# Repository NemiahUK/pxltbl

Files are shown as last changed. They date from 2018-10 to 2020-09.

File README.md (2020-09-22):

# Pixel Table 2.0 - Beta

Pixel Table

The API comes with a browser-based Emulator so you don’t need to build the table just yet.

## Try it out now - no hardware required!

You can now run the web-based emulator from any machine: Windows, Linux, Mac or RasPi. Follow the quick start guide and create 
progs that will run on a physical Pixel Table and play with them using a virtual Pixel Table in your browser. 

[Quick Start Guide](https://github.com/NemiahUK/pxltbl/blob/master/docs/getting-started.md)

## Costs

You have several options including software-only, table-top and full-sized. Each of these options can be done to different
levels of complexity and cost. Here's a rough guide to each option, a full bill of materials (BOM) can be found [HERE](https://docs.google.com/spreadsheets/d/1ZHOPDPXH3Y888mUGACTdFI8b1-cgUbUthqjndGLfB64).

### Software only - FREE

You can just download the API and use it on any machine via a web-browser. In future there will be a 'fullscreen' mode so that you 
can emulate the table top exactly as it would be on an actual pxltbl.

### PxlTbl Mini - £100 to £200

A table-top-sized device using a Raspberry Pi, 7" touchscreen and 3D printed case. You can add an audio HAT and arcade buttons too. 

### PxlTbl - £700 to £1,000

The full-sized version, over 1m long and 40cm high with a 50" touch screen. You can add a 200W stereo amp, car speakers, arcade buttons and
a real wood frame for an amazing looking and sounding piece of furniture. Or just keep things simple and costs low.

## Skills needed

Everything you need and where to buy them from will be listed in the [BOM](https://docs.google.com/spreadsheets/d/1ZHOPDPXH3Y888mUGACTdFI8b1-cgUbUthqjndGLfB64). You won't need to do any cutting, welding or custom 
fabrication, it's all based around pieces that can be ordered to size and bolted together. You will need to know how to solder
and if you have access to a 3D printer, laser cutter or CNC machine you can make the parts yourself instead of ordering them online.

## BIG plans

It's early days yet, but we have lots of great ideas. You can build "progs" using your web browser right now, then when we 
release the full build guid you can build your own table. 

## Hardware guide coming soon

We'll also be releasing a full guide on how to build your own Pixel Table using a RasPi + Arduino + NeoPixels. It's fairly straight
forward, and once built, you can use this API to make programming your table super-easy!

## API reference

[Full API reference (work in progress)](https://github.com/NemiahUK/pxltbl/blob/master/docs/api-reference.md) 

## Follow us

[Facebook](https://facebook.com/nemiah) - [Twitter](https://twitter.com/nemiahUK)

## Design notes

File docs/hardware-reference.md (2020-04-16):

# Hardware Reference

## GPIO Pins

                   3V3 -  1 2  - Arduino +5V
           Arduino SDA -  3 4  - Amp +5V
           Arduino SCL -  5 6  - Arduino GND
                       -  7 8  - Arduino UART Rx (Pin0)
               Amp GND -  9 10 - Arduino UART Tx (Pin1)
         Arduino Reset - 11 12 - Amp BCLK / Analog PWM L
             Button RT - 13 14 - GND
             Button TR - 15 16 - Button LB
            Button 3V3 - 17 18 - Button BL
                  MOSI - 19 20 - GND
                  MISO - 21 22 - Button LT
                  SCLK - 23 24 - CE0
                   GND - 25 26 - CE1
                       - 27 28 -
                       - 29 30 - GND
           Button Home - 31 32 - Button BR
          Analog PWM R - 33 34 - GND
             Amp LRCLK - 35 36 - Button RB
             Button TL - 37 38 - 
                   GND - 39 40 - Amp DIN

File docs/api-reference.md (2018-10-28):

# API Reference

## API functions

There are two ways to use the api.

#### Method 1 - Using "progs" via index.js

This is the simplest way to get up and running. Pixel Table has a basic "operating system" - index.js. This creates
a menu allowing you to run all the scripts in the progs/ directory. As well as providing easy access to settings. It 
also inculdes the API and makes it avaiable to your scripts in a simple way.

If you use this method, you simply create your script as-per the hello world example and upload it to the progs folder. 
You don't need to restart the running node process, you just go back to the home screen menu and select your prog. The 
system will reload your script from the file system and run it.

You don't need to initialise the api, you just put your code inside the setup() and loop() functions in your script.

    // Hello world example prog.

    // Put variables here that you need to persist between loops.
    var message = 'Hi =]';
    
    exports.setup = function(api) {
        // Code here get's executed once at program startup.
    
        // Blank the screen
        api.blank(0, 0, 0);
    };
    
    exports.loop = function(api) {
    
        // Set the drawing colour.
        api.setColor(0, 255, 0);
    
        // Print some text.
        api.text(message, 1,2);
    
        // If fire button pressed then exit back to home screen.
        if(api.buttons.topLeft) api.exit();
        
    };

Eventually you will also be able to create and upload progs via the web interface.

#### Method 2 - Creating your own script and including the API

If you don't want to use the menu system and have access to other progs etc you can just include the API. This way only
your script will run and you have more control over the system.

To initialise the API...

### start(options)

Initialises the API and returns a reference to it. The minimum you need is to set an FPS limit and callback function e.g.

    const api = require('./api.js');
    
    api = api.start({
        callbackLoop: myLoop,
        fpsLimit: 30
    });

The function myLoop() will then be called 30 times a second.

##### The options are...

 **callbackLoop** (function) *required - The function to call every frame
 
 **fpsLimit** (number) *recomended - The maximum FPS allowed. You can omit this or set to 0 but it's not advised, a 
 RasPi 3 runs around 100fps but without setting a limit animations will not be consistent unless you use time-based
 maths to animate things.
 
 **consoleData** (boolean) default: true - If true then show stats in console (updated every 500ms).
 
 ---
 
Whichever method you use, these functions can be used at any point.
 
### setFpsLimit(fps) 

Sets the FPS limit to fps.

---

### setRotation(angle)

Rotates both the display and buttons in 90deg increments.

The only valid options for angle are: 0, 90, 180 or 270.

---

### exit() 

Returns to the home screen - this only works if you are using the API from a prog called via index.js

---

### debug(string/object/array)

Outputs whatever is passed to it to the web interface as a debug message.

---

### error(string/object/array)

Outputs whatever is passed to it to the web interface as an error message.

---

### isRasPi

true if running on a Raspberry Pi, otherwise false.

---

### millis

Number of milliseconds since start, useful for time based animations and interactions.

---

### fps

Current FPS, 1 second average.

---

### frameTime

Last frame time in ms.

---

### pxlW

The width of the display in pixels.

---

### pxlH

The height of the display in pixels.

---

### pxlCount

The number of pixels in the display.

---

### pxlH

The height of the display in pixels.

## Drawing functions

For most draw functions you must first set the colour using setColor(), whatever colour is set will persist until 
setColor() is called again.

Pixel 0,0 is the top left pixel with the co-ordinates increasing in value as you move right or down.

The entire display can be rotated in 90deg increments using rotate() this will change the physical position of pixel 
0,0 accordingly.

### blank(r,g,b)
Fills the screen with the selected colour.

---

### setColor(r,g,b,[a])
Sets the drawing colour. 

`r,g,b` are values 0-255. `a` is optional, in the range of 0-1, default 1.0

---

### setColor(string)  *not yet implemented*
Sets the drawing colour.

String must be HTML/CSS Hex colour code. e.g. `#DECAFF`

---

### setColor(array)
Sets the drawing colour.

Expects an array of 3 or 4 elements...

    [0] = r    0-255
    [1] = g    0-255
    [2] = b    0-255
    [3] = a    0.0-1.0

---

### setColor(object)
Sets the drawing colour.

Possible object properties are...

RGB format

    {
        r : 0-255
        g : 0-255
        b : 0-255
        a : 0.0-1.0    //optional - default 1.0
    }
HSL format

    {
        h : 0-360
        s : 0-255
        l : 0-255
        a : 0.0-1.0    //optional - default 1.0
    }
HSV format

    {
        h : 0-360
        s : 0-255
        v : 0-255
        a : 0.0-1.0    //optional - default 1.0
    }

---

### setColorHsl(h,s,l,a)
Sets the drawing colour. 

`h` is 0-360, `s,l` are 0-255. `a` is optional, in the range of 0-1, default 1.0

---

### setColorHsv(h,s,v,a)
Sets the drawing colour. 

`h` is 0-360, `s,v` are 0-255. `a` is optional, in the range of 0-1, default 1.0

---

### fillBox(x,y,w,y)

Draws a filled box at location `x,y` of width `w` and height `h`

---

### text(text,x,y)

Draws `text` starting with the upper left corner of the first character at location `x,y`.

Returns an object containing the width and height of the bounding box containing the text.

    {
        w : width,
        h : height
    }

---

### textBounds(text)

Returns an object containing the width and height of the bounding box containing the text.

    {
        w : width,
        h : height
    }

---

## Input functions

Pixel table uses 8 control buttons at the corners of the table. These are named by the side they are on first 
followed by where they are on that side. So topLeft is on the TOP side at the LEFT and leftTop is on the LEFT side
at the TOP.

The top left button is where pixel 0,0 is located, it is not tied to a physical button. If the display is rotated (rotate()) then the names of the buttons will change
to match the device orientation, so topLeft will now be a different physical button, but it will still be where pixel 0,0 is.

### clearInputs()

Sets all buttons to false and clears all touch data.

---

### buttons

This variable is an object containing all the button states (true or false).

    {
        topLeft: true/false,
        leftTop: true/false,
        topRight: true/false,
        rightTop: true/false,
        rightBottom: true/false,
        bottomRight: true/false,
        bottomLeft: true/false,
        leftBottom: true/false,
        top: true/false,           // either top button has been pressed
        bottom: true/false,        // either bottom button has been pressed
        left: true/false,          // either left button has been pressed
        right: true/false,         // either right button has been pressed
        any: true/false            // any button has been pressed
    };
    
---

## Sound functions

### playWav(file,loop)

Plays a WAV file located in the `wav/` folder. There are over 500 wavs included in this repo and you can add your own.

file is just the filename without any path or extension. e.g. `sfx_damage_hit1`  will play `./wav/sfx_damage_hit1.wav`

If you set loop to true the WAV will continue to play until stopped. 

This function returns a reference that can be used to stop the playback. e.g.

    myPlayer = api.playWav('sfx_damage_hit1',true);
    ...
    myPlayer.stop();

## Helper functions

#### rgbToHsv(r,g,b)

---

#### hsvToRgb(h,s,v)

---

#### rgbToHsl(r,g,b)

---

#### hslToRgb(h,s,l)

To be continued....

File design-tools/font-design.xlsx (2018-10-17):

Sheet: lowercase
a | 1
 | 2
 | 4
 | 8 | 1 | 1 | 1 | 1 | 1
 | 16 |  |  |  |  | 1
 | 32 | 1 | 1 | 1 | 1 | 1
 | 64 | 1 |  |  |  | 1
 | 128 | 1 | 1 | 1 | 1 | 1
 | 61 | E8 | A8 | A8 | A8 | F8 | 61 | E8 | A8 | A8 | A8 | F8 | a
b | 1
 | 2 | 1
 | 4 | 1
 | 8 | 1 | 1 | 1 | 1 | 1
 | 16 | 1 |  |  |  | 1
 | 32 | 1 |  |  |  | 1
 | 64 | 1 |  |  |  | 1
 | 128 | 1 | 1 | 1 | 1 | 1
 | 62 | FE | 88 | 88 | 88 | F8 | 62 | FE | 88 | 88 | 88 | F8 | b
c | 1
 | 2
 | 4
 | 8 | 1 | 1 | 1 | 1 | 1
 | 16 | 1
 | 32 | 1
 | 64 | 1
 | 128 | 1 | 1 | 1 | 1 | 1
 | 63 | F8 | 88 | 88 | 88 | 88 | 63 | F8 | 88 | 88 | 88 | 88 | c
d | 1
 | 2 |  |  |  |  | 1
 | 4 |  |  |  |  | 1
 | 8 | 1 | 1 | 1 | 1 | 1
 | 16 | 1 |  |  |  | 1
 | 32 | 1 |  |  |  | 1
 | 64 | 1 |  |  |  | 1
 | 128 | 1 | 1 | 1 | 1 | 1
 | 64 | F8 | 88 | 88 | 88 | FE | 64 | F8 | 88 | 88 | 88 | FE | d
e | 1
 | 2
 | 4
 | 8 | 1 | 1 | 1 | 1 | 1
 | 16 | 1 |  |  |  | 1
 | 32 | 1 | 1 | 1 | 1 | 1
 | 64 | 1
 | 128 | 1 | 1 | 1 | 1 | 1
 | 65 | F8 | A8 | A8 | A8 | B8 | 65 | F8 | A8 | A8 | A8 | B8 | e
f | 1
 | 2 | 1 | 1 | 1 | 1
 | 4 | 1
 | 8 | 1 | 1 | 1
 | 16 | 1
 | 32 | 1
 | 64 | 1
 | 128 | 1
 | 66 | FE | A | A | 2 | 0 | 66 | FE | A | A | 2 | 0 | f
g | 1 | 1 | 1 | 1 | 1 | 1
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

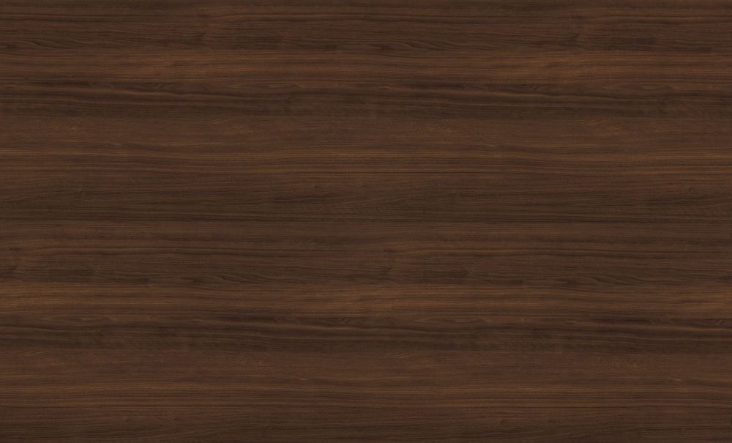
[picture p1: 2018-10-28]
api/web/bg.jpg

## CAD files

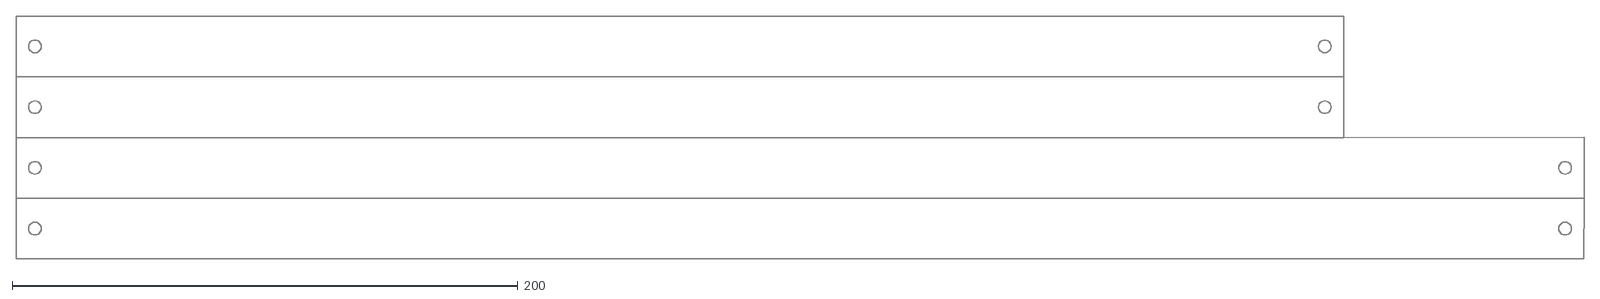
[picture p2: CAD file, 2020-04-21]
3d-print/short-side-panels-3mm.dxf
620.0 x 96.0

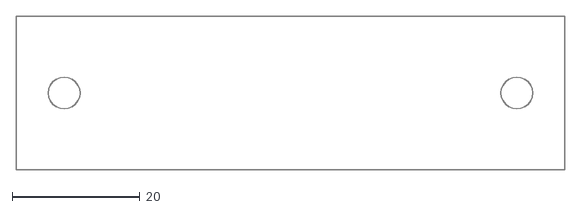
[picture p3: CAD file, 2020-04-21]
3d-print/short-side-panels-3mm-test.dxf
86.0 x 24.0

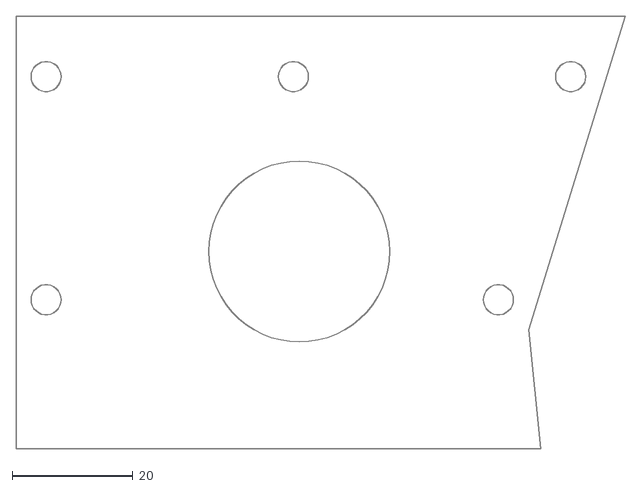
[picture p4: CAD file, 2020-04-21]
3d-print/short-side-panels-5mm-test.dxf
101.0 x 71.7

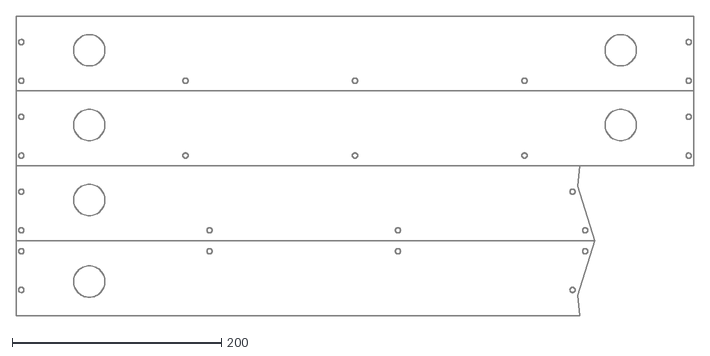
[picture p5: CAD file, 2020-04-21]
3d-print/short-side-panels-5mm.dxf
648.0 x 286.4

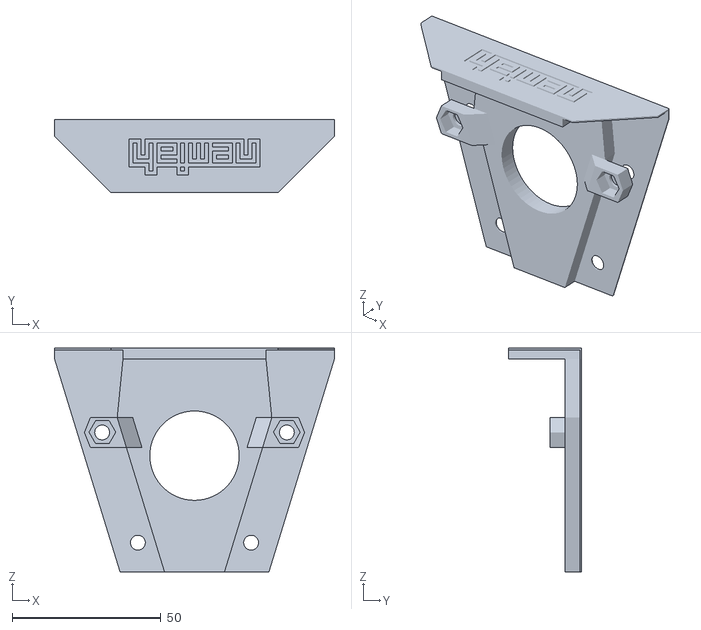
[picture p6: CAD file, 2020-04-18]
3d-print/short-button-joint.stl
94.0 x 24.6 x 75.1

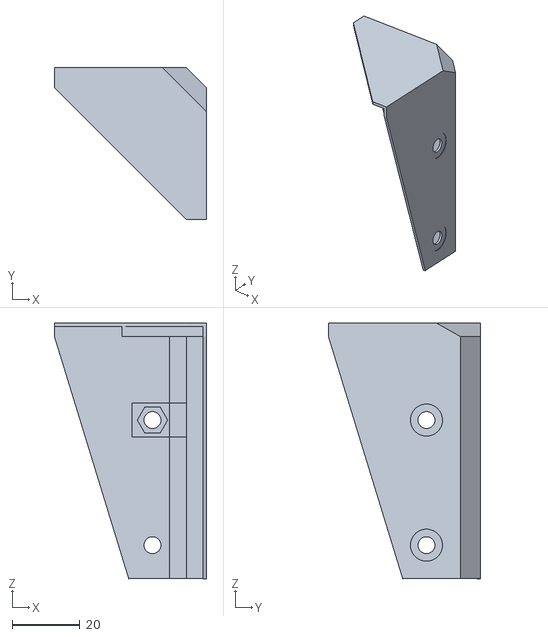
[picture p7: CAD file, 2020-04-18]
3d-print/short-corner-with-bracket.stl
45.0 x 45.0 x 75.7

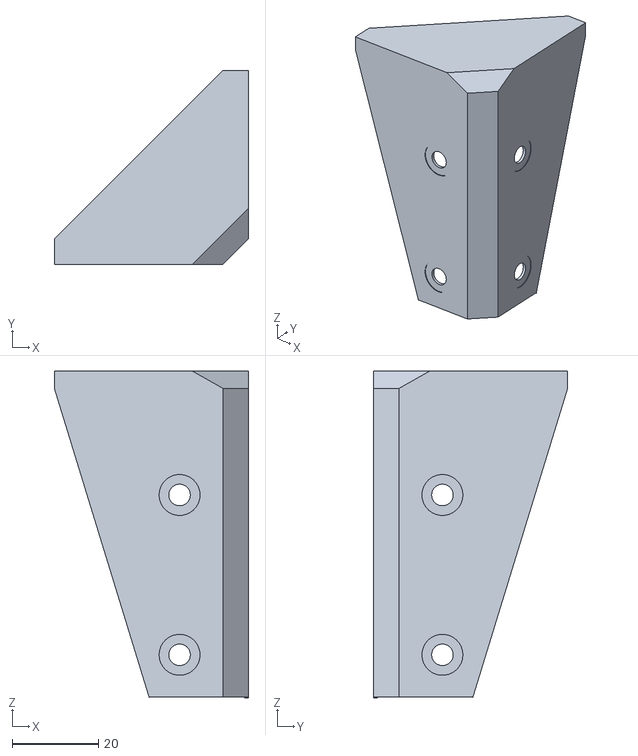
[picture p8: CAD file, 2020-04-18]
3d-print/short-corner.stl
45.0 x 45.0 x 75.7

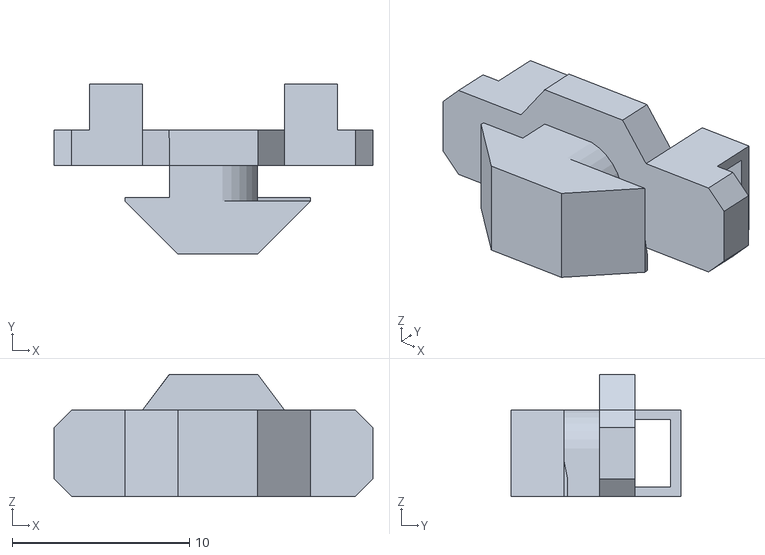
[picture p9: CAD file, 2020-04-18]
3d-print/cable-clip-5mm-slot.stl
18.0 x 9.60 x 6.89

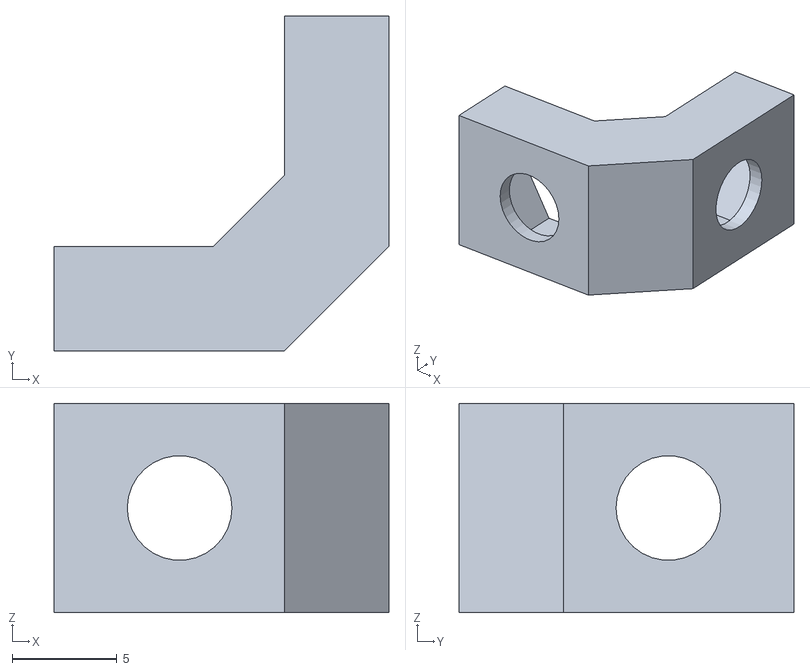
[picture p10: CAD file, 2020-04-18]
3d-print/M5-corner-bracket.stl
16.0 x 16.0 x 10.0

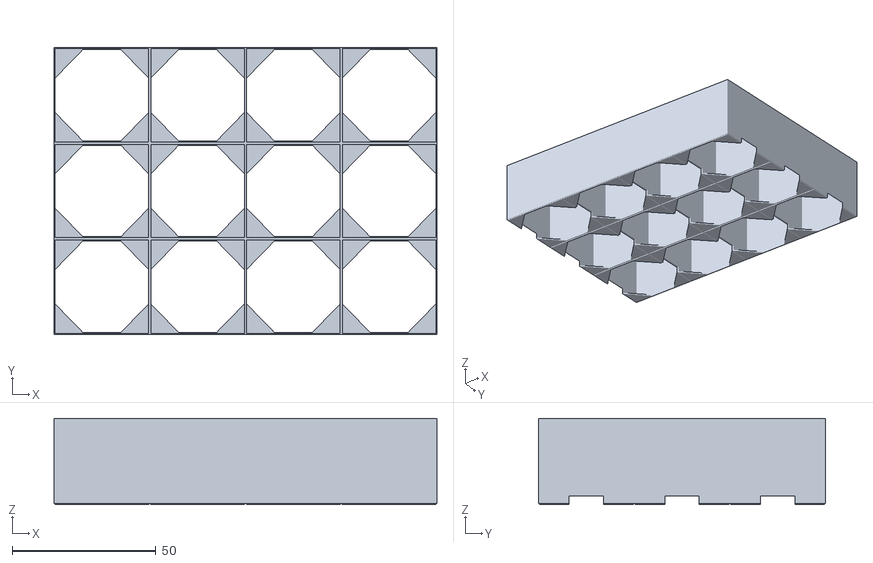
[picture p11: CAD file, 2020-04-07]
3d-print/reflector-33.3mm-30mm-4x3.stl
133.4 x 100.0 x 30.0

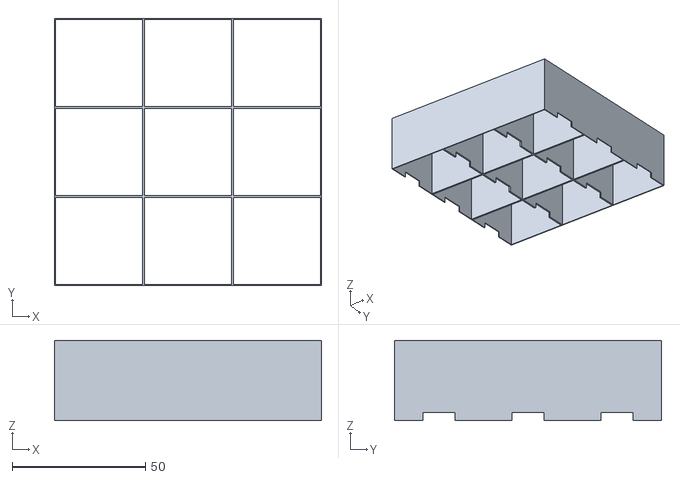
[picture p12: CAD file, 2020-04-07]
3d-print/reflector-33.3mm-30mm-3x3.stl
100.0 x 100.0 x 30.0

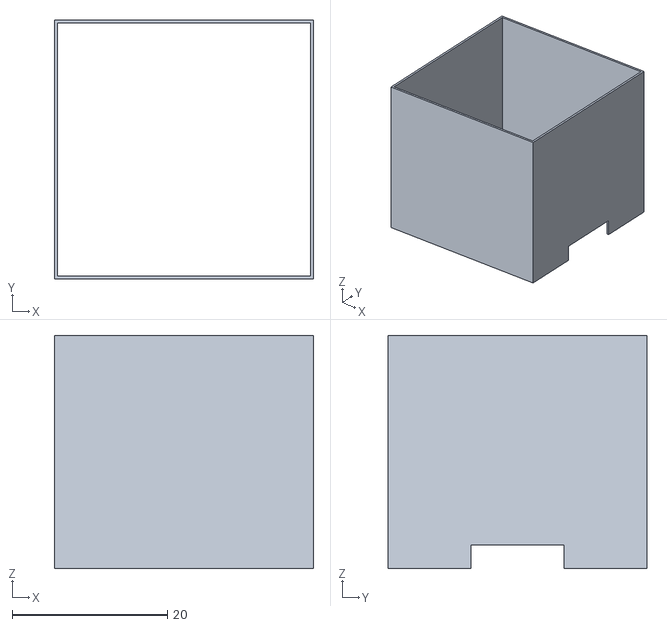
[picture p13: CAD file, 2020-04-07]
3d-print/reflector-33.3mm-30mm.stl
33.3 x 33.3 x 30.0

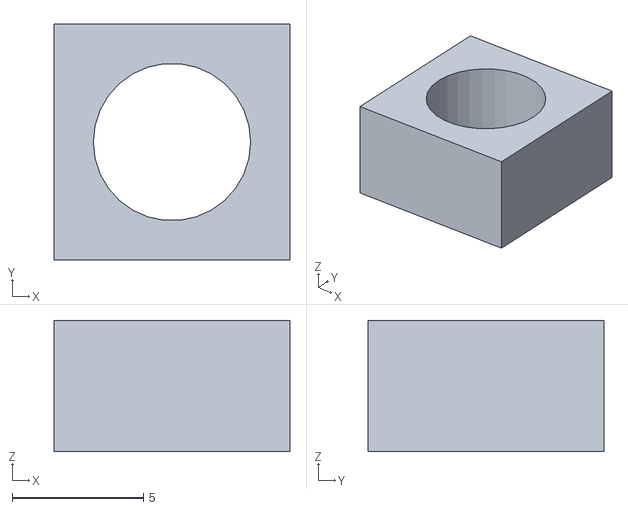
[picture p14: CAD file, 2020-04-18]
3d-print/M5-5x9x9mm-washer.stl
9.00 x 9.00 x 5.00

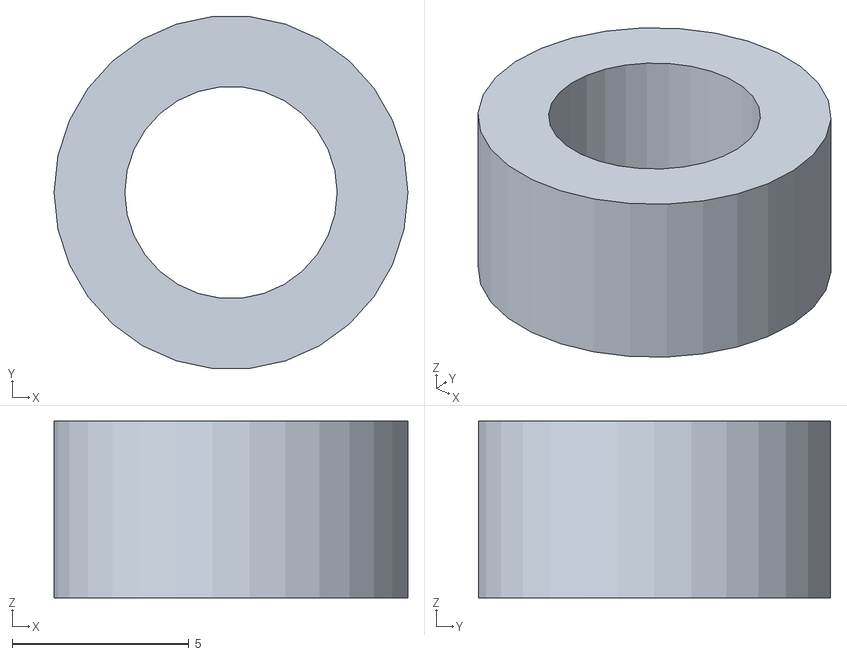
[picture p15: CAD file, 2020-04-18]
3d-print/M5-5x2mm-washer.stl
10.0 x 9.95 x 5.00

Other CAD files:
3d-print/full-model.skp
3d-print/wire-guide.skp

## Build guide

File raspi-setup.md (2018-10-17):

#RasPi Setup
##Enable audio over GPIO

add the following to /boot/config.txt: 

    dtoverlay=pwm-2chan,pin=18,func=2,pin2=13,func2=4

##Set screen res to 1600x900
Why? becasue this works really well for VNC on a 1080p monitor and is wide enough to display the LED buffer.

add the following to /boot/config.txt: 

    hdmi_group=2
    hdmi_mode=83

##RasPi config:

Enable SSH
Enable VNC
Enable I2C
Enable SPI
Enable Serial Port
Disable Serial Console

##Other config

Disable boot info (may already been done), edit this file: /boot/cmdline.txt and look for something liek this
    dwc_otg.lpm_enable=0 console=serial0,115200 console=tty1 root=/dev/mmcblk0p6 rootfstype=ext4 elevator=deadline rootwait

Delete the "console=serail0,115200" part.

##Install

###Arduino (in future this may be handled by node)

    sudo apt-get install arduino

###Arduino auto-reset script (in future this may be handled by node)

    cd ~
    wget https://github.com/SpellFoundry/avrdude-rpi/archive/master.zip
    sudo unzip master.zip
    cd ./avrdude-rpi-master/
    sudo cp autoreset /usr/bin
    sudo cp avrdude-autoreset /usr/bin
    sudo mv /usr/bin/avrdude /usr/bin/avrdude-original
    sudo ln -s /usr/bin/avrdude-autoreset /usr/bin/avrdude

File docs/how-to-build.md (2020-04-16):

# How to build the PxlTbl
## Coming soon...

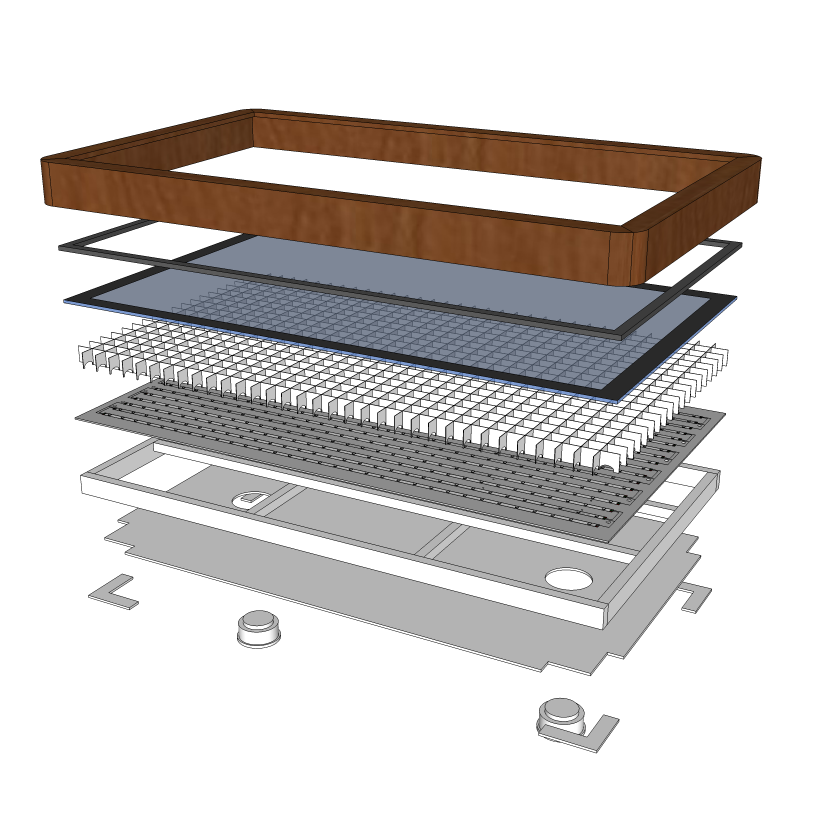
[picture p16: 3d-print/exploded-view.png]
Exploded view


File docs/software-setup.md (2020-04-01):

# RasPi Setup
## Enable audio over I2S

Follow the instructions here: https://learn.adafruit.com/adafruit-max98357-i2s-class-d-mono-amp/raspberry-pi-usage

## Set screen res to 1600x900
Why? becasue this works really well for VNC on a 1080p monitor and is wide enough to display the LED buffer.

add the following to /boot/config.txt: 

    hdmi_group=2
    hdmi_mode=83

## RasPi config:

* Enable SSH
* Enable VNC
* Enable I2C
* Enable SPI
* Enable Serial Port
* Disable Serial Console

## Other config

Disable boot info (this is usually already done), edit this file: `/boot/cmdline.txt` and look for something like this
    `dwc_otg.lpm_enable=0 console=serial0,115200 console=tty1 root=/dev/mmcblk0p6 rootfstype=ext4 elevator=deadline rootwait`

Delete the `console=serail0,115200` part.

## Enable auto run as service

Find out where npm is installed by typing `which npm` it should return `/usr/bin/npm` or `/usr/local/bin/npm` make a note of this.

Create the service file...

    sudo nano /etc/systemd/system/pxltbl.service

Paste the following:

    [Unit]
    Description=Pixel Table service
    After=network.target

    [Service]
    ExecStart=/usr/bin/npm start
    WorkingDirectory=/home/pi/pxltbl/api
    StandardOutput=inherit
    StandardError=inherit
    Restart=on-failure
    User=root

    [Install]
    WantedBy=multi-user.target

Change the line `ExecStart=/usr/bin/npm start` to match the npm path you noted down earlier.

Enable the service

    sudo systemctl enable pxltbl.service
   
Start the service

    sudo systemctl start pxltbl.service
    
If you want to view the logs

    journalctl -u pxltbl

## Install

### Prerequisites for node-hid

Compilation tools: 

    sudo apt-get install build-essential git

gcc-4.8+: 

    sudo apt-get install gcc-4.8 g++-4.8 && export CXX=g++-4.8

libusb-1.0-0 w/headers:

    sudo apt-get install libusb-1.0-0 libusb-1.0-0-dev

libudev-dev: 

    sudo apt-get install libudev-dev

### Arduino (in future this may be handled by node)

    sudo apt-get install arduino

### Arduino auto-reset script (in future this may be handled by node)

    cd ~
    wget https://github.com/SpellFoundry/avrdude-rpi/archive/master.zip
    sudo unzip master.zip
    cd ./avrdude-rpi-master/
    sudo cp autoreset /usr/bin
    sudo cp avrdude-autoreset /usr/bin
    sudo mv /usr/bin/avrdude /usr/bin/avrdude-original
    sudo ln -s /usr/bin/avrdude-autoreset /usr/bin/avrdude

## Reference

### GPIO Pins

                   3V3 -  1 2  - Arduino +5V
           Arduino SDA -  3 4  - Amp +5V
           Arduino SCL -  5 6  - Arduino GND
                       -  7 8  - Arduino UART Rx (Pin0)
               Amp GND -  9 10 - Arduino UART Tx (Pin1)
         Arduino Reset - 11 12 - Amp BCLK / Analog PWM L
             Button RT - 13 14 - GND
             Button TR - 15 16 - Button LB
            Button 3V3 - 17 18 - Button BL
                  MOSI - 19 20 - GND
                  MISO - 21 22 - Button LT
                  SCLK - 23 24 - CE0
                   GND - 25 26 - CE1
                       - 27 28 -
                       - 29 30 - GND
           Button Home - 31 32 - Button BR
          Analog PWM R - 33 34 - GND
             Amp LRCLK - 35 36 - Button RB
             Button TL - 37 38 - 
                   GND - 39 40 - Amp DIN

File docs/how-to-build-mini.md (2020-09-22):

# How to build the PxlTbl mini

# RasPi Setup

## Set screen res to 1024x600

Add the following to /boot/config.txt: 

    hdmi_cvt=1024 600 60 3 0 0 0
    hdmi_group=2
    hdmi_mode=87

## Using RasPi config:

* Enable SSH
* Enable VNC
* Enable Serial Port
* Disable Serial Console

## Other config

Disable boot info (this is usually already done), edit this file: `/boot/cmdline.txt` and look for something like this
    `dwc_otg.lpm_enable=0 console=serial0,115200 console=tty1 root=/dev/mmcblk0p6 rootfstype=ext4 elevator=deadline rootwait`

Delete the `console=serail0,115200` part.

## Setup audio shield

Follow the instructions at: https://learn.adafruit.com/adafruit-speaker-bonnet-for-raspberry-pi/raspberry-pi-usage

You need to complete the extra tasks on the I2S Tweaks page to get audio to work properly.

## Install

### Install node/npm

TODO

### Prerequisites for node-hid 

Compilation tools: 

    sudo apt-get install build-essential git

gcc-4.8+: 

    sudo apt-get install gcc-4.8 g++-4.8 && export CXX=g++-4.8

libusb-1.0-0 w/headers:

    sudo apt-get install libusb-1.0-0 libusb-1.0-0-dev

libudev-dev: 

    sudo apt-get install libudev-dev
    
## Configure pxltbl

Edit config.json and set `serialEnabled : false`

## Enable auto run as service

Copy service file

    sudo cp /home/pi/pxltbl/scripts/pxltbl.service /etc/systemd/system/pxltbl.service

Enable the service

    sudo systemctl enable pxltbl.service
   
Start the service

    sudo systemctl start pxltbl.service
    
If you want to view the logs

    journalctl -u pxltbl
    
## Disable screen blanking and pointer 
    sudo apt-get install unclutter xscreensaver        
  
##  Setup Chromium kiosk and auto boot  
Edit LXDE autostart
    
    sudo nano /etc/xdg/lxsession/LXDE-pi/autostart

add line
    
    @bash /home/pi/pxltbl/scripts/pxltbl-mini.sh
    
Change desktop background

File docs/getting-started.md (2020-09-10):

# Getting Started
#### A quick guide to setting up Pixel Table on your PC and creating your first prog.

Pixel Table Emulator

If you just want to use the web-based emulator instead of building your own Pixel Table, then this is the guide for you.

Pixel Table is designed to run on a Raspberry Pi 3+, but it should run on any platform that Node supports. We've tested it on Windows 10.

* Check to see if Node is already installed by typing `node -v` into the console
* If needed, Install Node.js you want the LTS version (currently v12) https://nodejs.org/en/download/ or 
in Ubuntu you can run the following command in terminal to install automatically `curl -sL https://deb.nodesource.com/setup_12.x | sudo -E bash -` then `sudo apt-get install -y nodejs npm` 
* *EITHER* install git (if needed) the clone the repo by typing  `git clone https://github.com/TmpR/pxltbl.git`
* *OR* Download the zip file from https://github.com/TmpR/pxltbl/archive/master.zip and extract it
* Navigate to the project directory and enter the sub-folder `api/` 
* Type `npm install`
* To run the app type `node index.js`
* Visit http://127.0.0.1:3000 in your browser

## Adding your own progs

* Navigate to the subfolder `progs/`
* Copy the `hello-world.js` file to `your-prog.js` create your own prog.

See https://github.com/NemiahUK/pxltbl/blob/master/docs/api-reference.md for more info on how to use the API.

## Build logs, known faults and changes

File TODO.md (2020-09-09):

# PxlTbl API Todo's

### Ideas

### TODO

- [ ] Move old 'package.json' and remove old node folder. Make sure new set up is working correctly.

### In Progress

### Done ✓

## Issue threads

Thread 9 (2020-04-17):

Sometimes when powering on Teensy crashes

Tmp2k, 2020-04-17:

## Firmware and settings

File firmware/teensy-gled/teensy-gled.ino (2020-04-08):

#include <OctoWS2811.h>


//OctoWS2811 Defn. Stuff
#define COLS_LEDS 32  
#define ROWS_LEDS 24  
#define SCREEN_ROWS_LEDS 18
#define RGB_ORDER "RGB"

#define LEDS_PER_STRIP (COLS_LEDS * (ROWS_LEDS / 8))
const int NUM_LEDS = (COLS_LEDS * ROWS_LEDS);

DMAMEM int displayMemory[LEDS_PER_STRIP*6];
int drawingMemory[LEDS_PER_STRIP*6];

const int config = WS2811_GRB | WS2811_800kHz;
OctoWS2811 leds(LEDS_PER_STRIP, displayMemory, drawingMemory, config);

//Params and global variables
#define LOGO_COLOR #CCCCCC
#define BAUD 1000000

unsigned long lastSerialRead = 0;


//Logo anim stuff
#define ANIM_FPS 40
int pxl = 0;
unsigned long lastFrameTime = 0;
unsigned int paintColor;
int logoX, logoY, logoScroll, yPos;
float xPos = -7, xScroll = 0;
int animState = 0;

//rainbow colors..
//Hue => [0,45,65,135,210,260,270]
byte rainbowR[] = {255, 255, 234,   0,   0,  85, 128};
byte rainbowG[] = {  0, 191, 255, 255, 128,   0,   0};
byte rainbowB[] = {  0,   0,   0,  64, 255, 255, 255};


void setup() {
  
  Serial1.begin(BAUD);
  //Serial.begin(BAUD);
  leds.begin();
  leds.show();
}

int serialGlediator() {
  while (!Serial1.available() && !Serial.available()) {
    if(millis() - lastSerialRead > 1000) showLogo();
  }
  if(Serial.available()) {
    resetLogo();
    return Serial.read();
  } else {
    resetLogo();
    return Serial1.read();
  }
}



void loop() {
  
  byte mode = 0;

  while (serialGlediator() != 1) {}
  mode = serialGlediator();

  switch (mode) {
    case 0x2:
      readFrame();
      break;
    case 0x3:
      returnInfo();
      break;
  }
}



void resetLogo() {
  lastSerialRead = millis();
  xPos = -7;
  xScroll = 0;
}

void showLogo() {
  int i,j,y;

  if(millis() - lastFrameTime < 1000 / ANIM_FPS) return;  //40FPS
  lastFrameTime = millis();
 
  blank(0x000000);

  yPos = SCREEN_ROWS_LEDS / 2 - 3;  //Approx horz middle of screen - 1/2 logo height

  logoX = round(xPos);
  logoScroll = round(xScroll);
  logoY = round(yPos);
  if(logoX % 6 < 3) logoY--;

  //logo
  paintColor = 0x333333;
  setPixel(logoX-logoScroll,logoY+0); setPixel(logoX-logoScroll+1,logoY+0); setPixel(logoX-logoScroll+2,logoY+0); setPixel(logoX-logoScroll+3,logoY+0); setPixel(logoX-logoScroll+4,logoY+0); setPixel(logoX-logoScroll+5,logoY+0); setPixel(logoX-logoScroll+6,logoY+0);
  setPixel(logoX-logoScroll,logoY+1); setPixel(logoX-logoScroll+6,logoY+1); 
  setPixel(logoX-logoScroll,logoY+2); setPixel(logoX-logoScroll+2,logoY+2); setPixel(logoX-logoScroll+3,logoY+2); setPixel(logoX-logoScroll+4,logoY+2); setPixel(logoX-logoScroll+6,logoY+2);
  setPixel(logoX-logoScroll,logoY+3); setPixel(logoX-logoScroll+2,logoY+3); setPixel(logoX-logoScroll+4,logoY+3); setPixel(logoX-logoScroll+6,logoY+3);
  setPixel(logoX-logoScroll,logoY+4); setPixel(logoX-logoScroll+2,logoY+4); setPixel(logoX-logoScroll+4,logoY+4); setPixel(logoX-logoScroll+6,logoY+4);
  setPixel(logoX-logoScroll,logoY+5); setPixel(logoX-logoScroll+2,logoY+5); setPixel(logoX-logoScroll+4,logoY+5); setPixel(logoX-logoScroll+6,logoY+5);
  setPixel(logoX-logoScroll,logoY+6); setPixel(logoX-logoScroll+1,logoY+6); setPixel(logoX-logoScroll+2,logoY+6); setPixel(logoX-logoScroll+4,logoY+6); setPixel(logoX-logoScroll+5,logoY+6); setPixel(logoX-logoScroll+6,logoY+6); 

  //rainbow
  for (j=0; j < 8; j++) {
        for (i = 0; i < 7; i++) {
            y = yPos;
            if((logoX-j)%6 < 3) y--;
            float alpha = 1-j/9.0;
            paintColor = Color(alpha*rainbowR[i],alpha*rainbowG[i],alpha*rainbowB[i]);
            setPixel(logoX - j - 1-logoScroll, i + y);
        }
    }

    if(animState == 0) {
        xPos+=0.2;
    } else {
        xPos+=1;
    }
    if(xPos > COLS_LEDS/2 && animState == 0) xScroll+=0.2;



    //prevent overflow
    if(xPos >= (COLS_LEDS/2)+6 && animState == 0) {
        xPos = (COLS_LEDS/2);
        xScroll = 0;
    }


    if(xPos-xScroll > COLS_LEDS){
        //animation complete
    }


  if(!leds.busy()) leds.show();
}

void readFrame() {
  byte r,g,b;
  int x,y,i;
  
  for (y=0; y < ROWS_LEDS; y++) {
    for (x=0; x < COLS_LEDS; x++) {
    
      r = serialGlediator();
      g = serialGlediator();
      b = serialGlediator();

      //if we recieve a 1 then exit out of this loop
      if(r == 1 || g == 1 || b == 1) {
        leds.show();
        return;
      }

      if(y % 6 < 3) { 
        if(y % 2) { //Usual postion
          i = (y+1)*COLS_LEDS - (x+1); 
        } else {
          i = y*COLS_LEDS + x; 
        }
      } else { //Every 3 rows we swap the "snake" pattern
        if(y % 2) {
          i = y*COLS_LEDS + x;
        } else {
          i = (y+1)*COLS_LEDS - (x+1); 
        }
      }

      leds.setPixel(i, Color(r,g,b));
      
    }
  }
  leds.show();
}

void returnInfo() {
 
  Serial.println("PxlTbl v1.0 - Params: Number of LEDs, Screen Width, Screen Height, Baud rate, RGB Order, Start, Serpantine");
  Serial.println(NUM_LEDS);
  Serial.println(COLS_LEDS);
  Serial.println(SCREEN_ROWS_LEDS);
  Serial.println(BAUD);
  Serial.println(RGB_ORDER);

  Serial1.println("PxlTbl v1.0 - Params: Number of LEDs, Screen Width, Screen Height, Baud rate, RGB Order, Start, Serpantine");
  Serial1.println(NUM_LEDS);
  Serial1.println(COLS_LEDS);
  Serial1.println(SCREEN_ROWS_LEDS);
  Serial1.println(BAUD);
  Serial1.println(RGB_ORDER);


}

/* Helper functions */

//set pixel based on X,Y
void setPixel(int x,int y) {
  int i;

  if(x < 0 || x >= COLS_LEDS) return;
  if(y < 0 || y >= ROWS_LEDS) return;

  if(y % 6 < 3) {  //Usual postion
    if(y % 2 ==0) {
      i = y*COLS_LEDS + x; 
    } else {
      i = (y+1)*COLS_LEDS - (x+1); 
    }
  } else { //Every 3 rows we swap the "snake" pattern
    if(y % 2 ==0) {
      i = (y+1)*COLS_LEDS - (x+1);
    } else {
      i = y*COLS_LEDS + x;  
    } 
  }

  leds.setPixel(i, paintColor);
  
}

//Fill all pixels with a colour
void blank(unsigned int color) {
  int i;
  for (i = 0; i < NUM_LEDS; i++) {
    leds.setPixel(i, color);
  }
}

// Create a 24 bit color value from R,G,B
unsigned int Color(byte r, byte g, byte b)
{
  return (((unsigned int)r << 16) | ((unsigned int)g << 8) | (unsigned int)b);
}

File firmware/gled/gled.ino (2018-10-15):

//##############################################################################
//##############################################################################
//                                                                             #
// Glediator to WS2812 pixel converter                                         #
// by R. Heller                                                                #
// V 1.0 - 07.01.2014                                                          #            
// wwww.SolderLab.de                                                           #
//                                                                             #
// Receives serial data in Glediator protocol format @ 1 MBit/s                #
// and distributes it to a connectect chain of WS2812 pixels                   #
//                                                                             #
// Adjust the correct DATA PIN and the correct NUMBER OF PIXELS you are using  # 
// in the definitions section below before uploading this sketch to your       #
// Arduino device.                                                             #
//                                                                             #
// Maxiumim number of supported pixeles is 512 !!!                             #
//                                                                             #
// In the Glediator software set output mode to "Glediator_Protocol",          #
// color order to "GRB" and baud rate to "1000000"                             #
//                                                                             #
//##############################################################################
//##############################################################################


//##############################################################################
//                                                                             #
// Definitions --> Make changes ONLY HERE                                      #
//                                                                             #
// To find out the correct port, ddr and pin name when you just know the       #
// Arduino's digital pin number just google for "Arduino pin mapping".         #
// In the present example digital Pin 6 is used which corresponds to "PORTD",  #
// "DDRD" and "6", respectively.                                               #
//                                                                             #
//##############################################################################

#define DATA_PORT          PORTD
#define DATA_DDR           DDRD						
#define DATA_PIN           6							
#define NUMBER_OF_PIXELS   253

//====NOT CURRENTLY USED========
#define FCPU 16000000
#define baud 1000000
#define myubrr FCPU/16/baud - 1
//==============================

//##############################################################################
//                                                                             #
// Variables                                                                   #
//                                                                             #
//##############################################################################

unsigned char display_buffer[NUMBER_OF_PIXELS * 3];
static unsigned char *ptr;
static unsigned int pos = 0;

volatile unsigned char go = 0;


//##############################################################################
//                                                                             #
// Setup                                                                       #
//                                                                             #
//##############################################################################

void setup()
{

  //need to add a startup animation here,  then wait for signal from RasPi

  // Set data pin as output
  DATA_DDR |= (1 << DATA_PIN);


  // Initialize UART
  UCSR0A |= (1<<U2X0);
  UCSR0B |= (1<<RXEN0)  | (1<<TXEN0) | (1<<RXCIE0);
  UCSR0C |= (1<<UCSZ01) | (1<<UCSZ00)             ;
  UBRR0H = 0;
  UBRR0L = 1; //Baud Rate 1 MBit (at F_CPU = 16MHz)

  ptr=display_buffer;

  //Enable global interrupts
  sei();
}


//##############################################################################
//                                                                             #
// Main loop                                                                   #
//                                                                             #
//##############################################################################

void loop()
{
  if (go==1)
  {
    cli();
    ws2812_sendarray(display_buffer, NUMBER_OF_PIXELS * 3);
    sei();
    go=0;
  }
}


//##############################################################################
//                                                                             #
// UART-Interrupt-Prozedur (called every time one byte is compeltely received) #
//                                                                             #
//##############################################################################

ISR(USART_RX_vect)
{
  unsigned char b;
  b=UDR0;

  if (b == 1)  {pos=0; ptr=display_buffer; return;}
  if (pos == (NUMBER_OF_PIXELS*3)) {} else {*ptr=b; ptr++; pos++;}
  if (pos == ((NUMBER_OF_PIXELS*3)-1)) {go=1;}
}


//##############################################################################
//                                                                             #
// WS2812 output routine                                                       #
// Extracted from a ligh weight WS2812 lib by Tim (cpldcpu@gmail.com)          #
// Found on wwww.microcontroller.net                                           #
// Requires F_CPU = 16MHz                                                      #
//                                                                             #
//##############################################################################

void ws2812_sendarray(uint8_t *data,uint16_t datlen)
{
  uint8_t curbyte,ctr,masklo;
  uint8_t maskhi = _BV(DATA_PIN);
  masklo =~ maskhi & DATA_PORT;
  maskhi |= DATA_PORT;

  while (datlen--)
  {
    curbyte = *data++;

    asm volatile
    (
      "		ldi %0,8	\n\t"		// 0
      "loop%=:out %2, %3	\n\t"		// 1
      "lsl	%1		\n\t"		// 2
      "dec	%0		\n\t"		// 3
      "		rjmp .+0	\n\t"		// 5
      "		brcs .+2	\n\t"		// 6l / 7h
      "		out %2,%4	\n\t"		// 7l / -
      "		rjmp .+0	\n\t"		// 9
      "		nop		\n\t"		// 10
      "		out %2,%4	\n\t"		// 11
      "		breq end%=	\n\t"		// 12      nt. 13 taken
      "		rjmp .+0	\n\t"		// 14
      "		rjmp .+0	\n\t"		// 16
      "		rjmp .+0	\n\t"		// 18
      "		rjmp loop%=	\n\t"		// 20
      "end%=:			\n\t"
      :	"=&d" (ctr)
      :	"r" (curbyte), "I" (_SFR_IO_ADDR(DATA_PORT)), "r" (maskhi), "r" (masklo)
    );
  }

}
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

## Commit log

2018-10-15 added fonts, removed RGBA from every functiona and added setColor
    [font.xlsx]
2018-10-17 updated example progs
    [font.xlsx]
2018-10-17 added raspi setup instructions
    [font-export.csv, font.csv]
2018-10-20 added vagrant, physical buttons etc
2018-10-26 changed to edge buttons, updated test prog, added fritzing files
    [debounce.fzz, micro.fzz]
2020-03-12 Working on sname game. Error handling improved to display message clearly.
    [api.js]
2020-04-01 Changed to Teensy USB serial and RGB instead of GRB
2020-04-01 added teensy firmware
2020-04-07 added 3D files, moved serpantine processing to teensy, added query hardware params and lots more
    [full-model.skp, reflector-33.3mm-15mm-3x3.stl, reflector-33.3mm-15mm.stl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]
2020-04-07 added frame data size and bandwidth to console log
2020-04-08 fixed nemiah logo prog, made menu much nicer and animated
    [api.js, teensy-gled.ino]
2020-04-13 added al kinds of cool stuff. 3D models, a new game, refined touch interface etc etc
    [full-model.skp]
2020-04-18 updated 3D model, created some new 3D printed parts
    [M5-5x2mm-washer.stl, M5-5x9x9mm-washer.stl, M5-corner-bracket.stl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]
2020-04-21 added support for PxlTbl mini
    [full-model.skp, reflector-33.3mm-15mm-3x3.stl, reflector-33.3mm-15mm.stl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]
2020-05-26 updated pong game - now playable! few API fixes
    [api.js]
2020-09-10 :construction: Still working on API v2. Sound not working and hardware support needs improving but everything else is getting there now.
    [api.js]
2020-09-10 added touch/button inputs
2020-09-10 added VScode debug info / fixed error [object] instead of string
    [api.js]
2020-09-10 converted hello world to API v2 and added error message helpers
    [api.js]
2020-09-10 added more error message helpers
    [api.js]
2020-09-15 :construction: Working on fixing drop
    [api.js]
2020-09-21 getting HID working from conf file / removed speaker package / updated pxltbl mini scripts / fixed fullscreen.html
    [api.js]
2020-09-22 adding multiple serial device retry
2020-09-24 fixing buttons / updating scripts / create HW test prog
    [api.js]
2020-09-25 added design tools
    [font-design.xlsx, screen-design.xlsx]
2020-09-25 added ambient prog / fixed HID crash detection
    [api.js]
2020-10-10 trapping audio device errors and setting default HTTP port to 80
    [api.js]
2020-10-10 trapping audio device errors a
    [api.js]
2020-10-10 trapping audio device errors
    [api.js]
